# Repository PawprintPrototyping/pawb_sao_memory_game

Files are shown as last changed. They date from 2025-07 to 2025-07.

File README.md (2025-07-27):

# Paw SAO Memory Game

front

A [SAO](https://badge.team/docs/standards/sao/) shaped like a Paw that can play a memory game.  Opensource, originally designed for 
[Opensauce](https://opensauce.com) 2025 to encourage experimentation with microcontroller programming with the CH32V003F4P6.

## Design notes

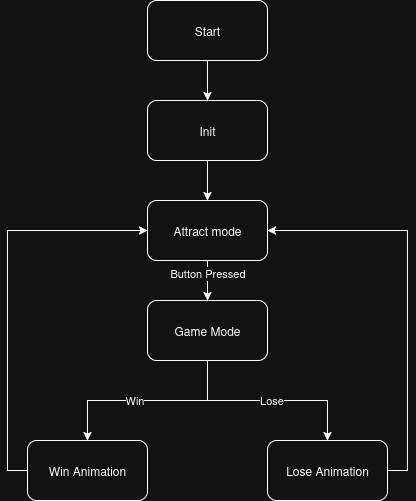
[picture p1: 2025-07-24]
software/planning/main_state_machine.drawio.png

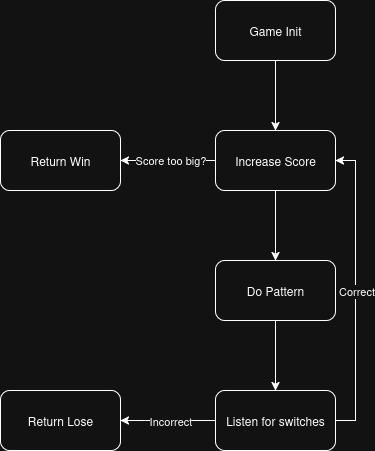
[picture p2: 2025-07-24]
software/planning/game_state_machine.drawio.png

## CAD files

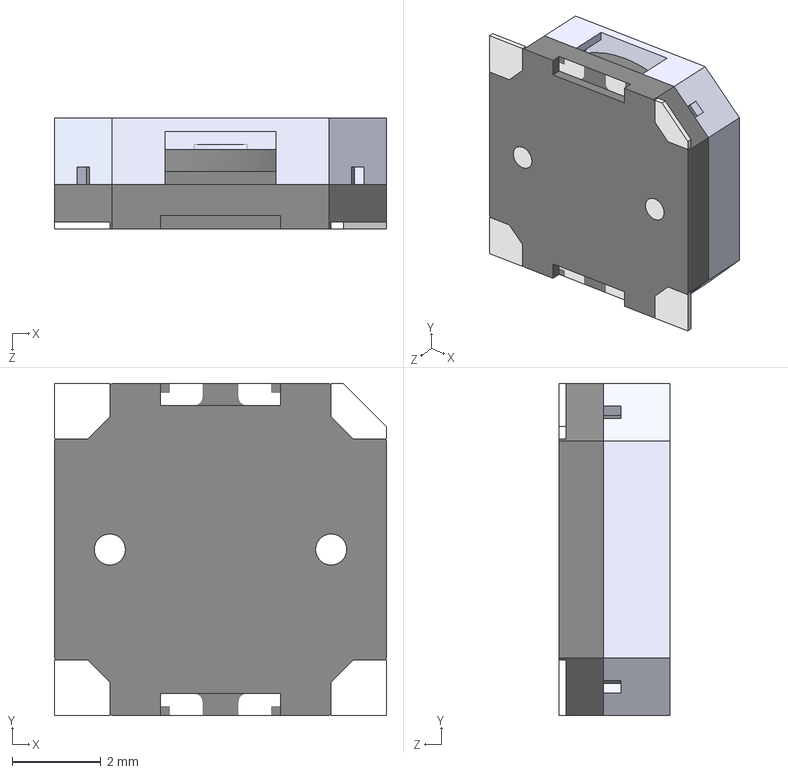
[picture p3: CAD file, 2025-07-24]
hardware/3d/OWMB-757525S-27-15A_3D_CAD.STEP
7.50 x 7.50 x 2.50 mm
7525AS gu jia
7525AS GAI

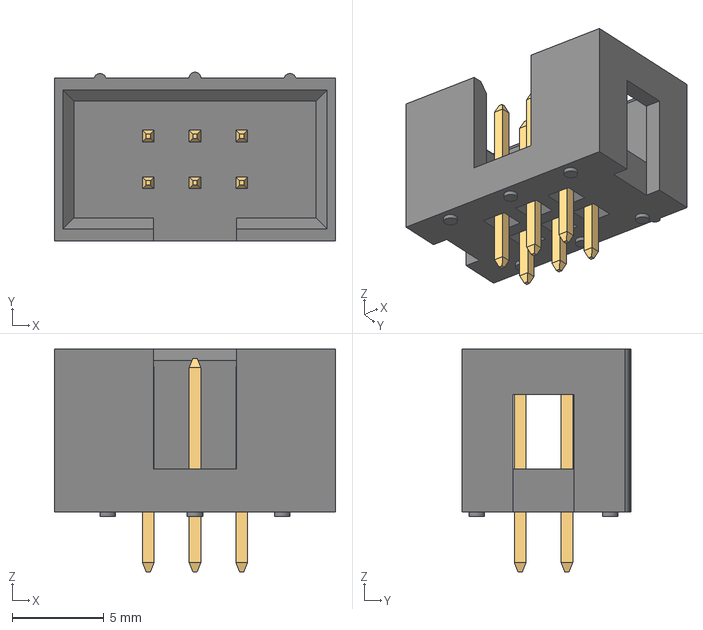
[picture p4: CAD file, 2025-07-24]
hardware/3d/61200621621+(rev1).stp
15.3 x 9.18 x 12.1 mm
6120xx21621_PIN x 6

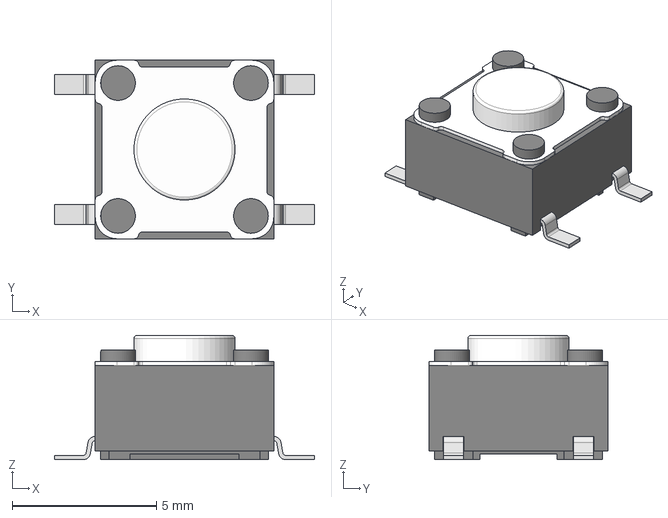
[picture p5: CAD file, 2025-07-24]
hardware/3d/430182043816+(rev1).stp
9.00 x 6.20 x 4.30 mm

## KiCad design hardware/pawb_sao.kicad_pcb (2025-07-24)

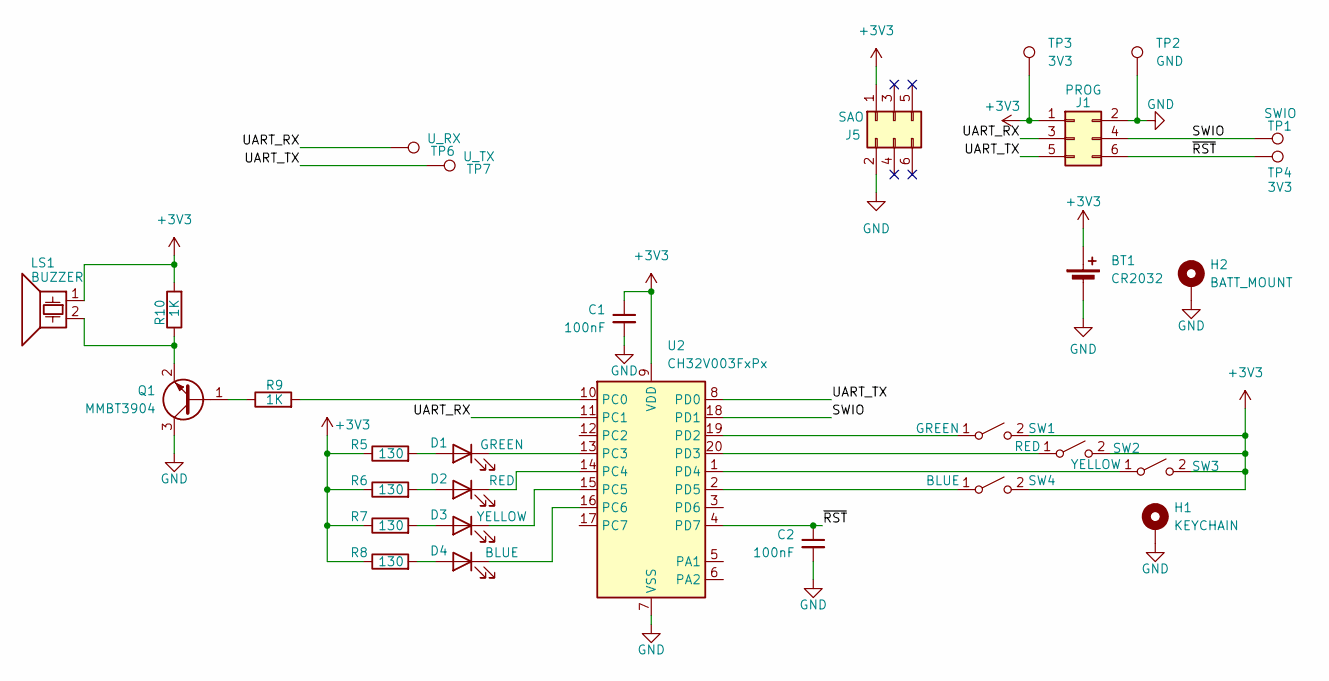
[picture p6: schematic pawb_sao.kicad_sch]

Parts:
BT1: CR2032; BH-25C-1_ADM_EZ
C1, C2: 100nF; C_0402_1005Metric
D1: GREEN; LED_0805_2012Metric
D2: RED; LED_0805_2012Metric
D3: YELLOW; LED_0805_2012Metric
D4: BLUE; LED_0805_2012Metric
H1: KEYCHAIN; MountingHole_3.2mm_M3_Pad_Via
H2: BATT_MOUNT; MountingHole_2.2mm_M2
J1: PROG; Paw-Connect_RevB_TC2030-IDC-NL_2x03_P1.27mm_Vertical
J5: SAO; PinHeader_2x03_P2.54mm_Vertical
LS1: BUZZER; FUET-9018
Q1: MMBT3904; SOT-23
R5, R6, R7, R8: 130; R_0603_1608Metric
R9, R10: 1K; R_0402_1005Metric
SW1: GREEN; SW_SPST_EVQP0
SW2: RED; SW_SPST_EVQP0
SW3: YELLOW; SW_SPST_EVQP0
SW4: BLUE; SW_SPST_EVQP0
TP1: SWIO; TestPoint_Pad_D1.5mm
TP2: GND; TestPoint_Pad_D1.5mm
TP3, TP4: 3V3; TestPoint_Pad_D1.5mm
TP6: U_RX; TestPoint_Pad_D1.5mm
TP7: U_TX; TestPoint_Pad_D1.5mm
U2: CH32V003FxPx; TSSOP-20_4.4x6.5mm_P0.65mm

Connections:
+3V3: BT1.1 (+), C1.1, J1.1, J5.1, LS1.1, R5.1, R6.1, R7.1, R8.1, R10.2, SW1.2 (B), SW2.2 (B), SW3.2 (B), SW4.2 (B), TP3.1, U2.9 (VDD)
/SWIO: J1.4, TP1.1, U2.18 (PD1)
/UART_RX: J1.3, TP6.1, U2.11 (PC1)
/UART_TX: J1.5, TP7.1, U2.8 (PD0)
/~RST: C2.1, J1.6, TP4.1, U2.4 (PD7)
GND: BT1.2 (-), C1.2, C2.2, H1.MP, H2.MP, J1.2, J5.2, Q1.3 (C), TP2.1, U2.7 (VSS)
unnamed: D1.2 (A), R5.2
unnamed: D1.1 (K), U2.13 (PC3)
unnamed: D2.2 (A), R6.2
unnamed: D2.1 (K), U2.14 (PC4)
unnamed: D3.2 (A), R7.2
unnamed: D3.1 (K), U2.15 (PC5)
unnamed: D4.2 (A), R8.2
unnamed: D4.1 (K), U2.16 (PC6)
unnamed: Q1.1 (B), R9.1
unnamed: LS1.2, Q1.2 (E), R10.1
unnamed: SW1.1 (A), U2.19 (PD2)
unnamed: SW2.1 (A), U2.20 (PD3)
unnamed: SW3.1 (A), U2.1 (PD4)
unnamed: SW4.1 (A), U2.2 (PD5)
unnamed: R9.2, U2.10 (PC0)

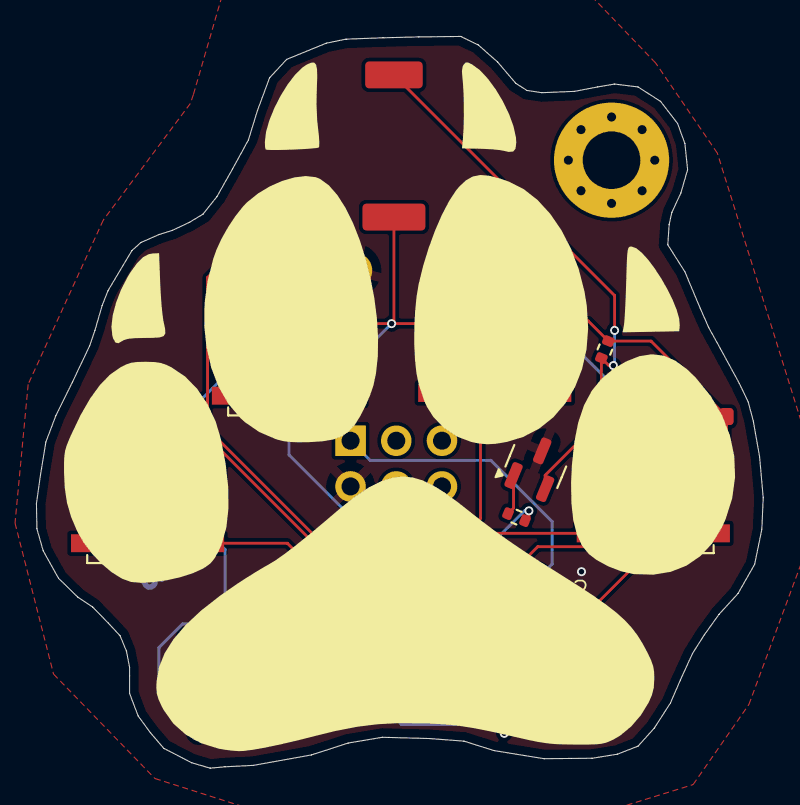
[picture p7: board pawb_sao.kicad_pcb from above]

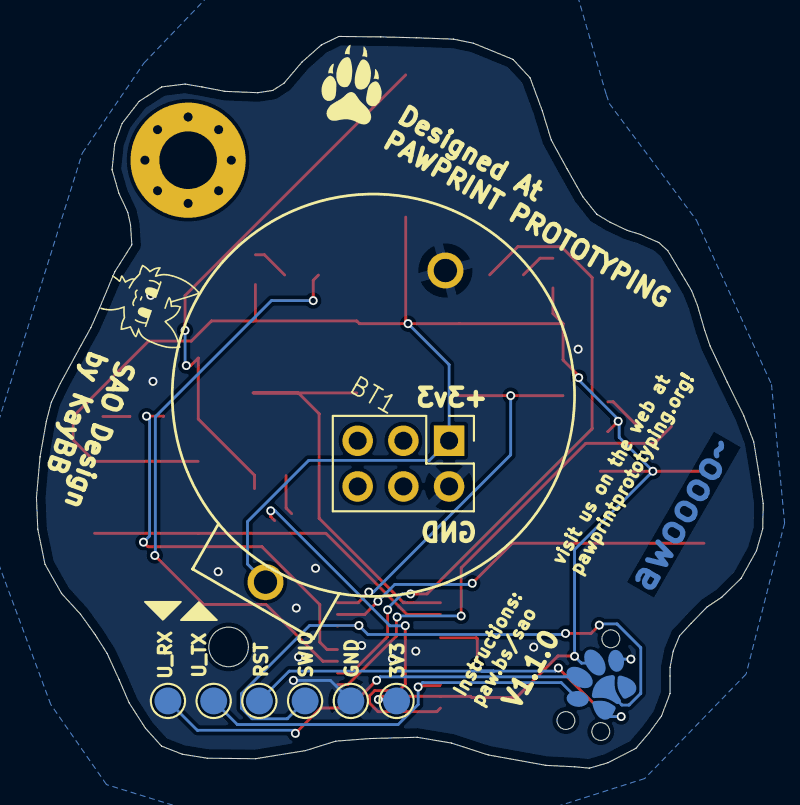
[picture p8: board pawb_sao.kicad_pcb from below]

Board: 2 copper layers, 40.4 x 40.6 mm, 30 parts (9 on the bottom side), 21 nets.

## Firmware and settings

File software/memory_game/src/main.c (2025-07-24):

#include "ch32fun.h"
#include <stdio.h>

// Project Includes
#include "periphs.h"
#include "game.h"
#include "attract.h"


void init(){
	init_gpio();
	seedrand();
}

void power_on_self_test(){
	for(uint8_t i = 0; i < 3; i++)
	{
		led_on(GREEN_LED);
		led_on(RED_LED);
		led_on(YELLOW_LED);
		led_on(BLUE_LED);
		Delay_Ms( 100 );
		led_off(GREEN_LED);
		led_off(RED_LED);
		led_off(YELLOW_LED);
		led_off(BLUE_LED);
		Delay_Ms( 100 );
	}
	beep(GREEN_SW, 10);
	beep(RED_SW, 10);
	beep(YELLOW_SW, 10);
	beep(BLUE_SW, 10);
}

int main()
{
	SystemInit();
    init();
	power_on_self_test();

	while(1){
		attract();
		Delay_Ms(1000);
		game_loop();
	}
}

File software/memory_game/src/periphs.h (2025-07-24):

#ifndef _PERIPHS_H
#define _PERIPHS_H

#include "ch32fun.h"

#define NUM_COLORS  4

#define GREEN_LED   PC3
#define RED_LED     PC4
#define YELLOW_LED  PC5
#define BLUE_LED    PC6

#define GREEN_SW    PD2
#define RED_SW      PD3
#define YELLOW_SW   PD4
#define BLUE_SW     PD5

#define PIEZO_SPK   PC0

#define GREEN_NOTE	1908	
#define RED_NOTE	1515
#define YELLOW_NOTE	1276
#define BLUE_NOTE	956
#define LOSS_NOTE	5745

static uint8_t leds[] = {GREEN_LED, RED_LED, YELLOW_LED, BLUE_LED};
static uint8_t sws[] = {GREEN_SW, RED_SW, YELLOW_SW, BLUE_SW};

// Given a LED, return its switch
uint8_t led_to_sw(uint8_t led);

// Given a switch, return its LED
uint8_t sw_to_led(uint8_t sw);

// Beep for a given time
void beep(uint8_t sw, uint32_t time);

// Init all the GPIOs
void init_gpio();

// Set the state of an LED
void set_led(uint8_t led, uint8_t state);

// Set the state of all the LEDs at once
void set_all_leds(uint8_t state);

// Turn on an LED
void led_on(uint8_t led);

// Turn off an LED
void led_off(uint8_t led);

// Read a switch and beep. Might need to debounce this
uint8_t sw_read(uint8_t sw);

// Poll all the switches, return the switch that is pressed, 0 otherwise
uint8_t poll_switches();


#endif
